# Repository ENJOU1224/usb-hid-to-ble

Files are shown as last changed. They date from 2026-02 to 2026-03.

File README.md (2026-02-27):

# USB HID to BLE Adapter (ENJOU Wireless Adapter)

一个基于 CH583 RISC-V 微控制器的 USB HID 到 BLE 适配器，可以将 USB 键盘和鼠标转换为蓝牙低功耗 (BLE) HID 设备。

## 项目概述

本项目实现了一个 USB Host 到 Bluetooth Low Energy (BLE) 的桥接器，将 USB HID（人机接口设备）键盘和鼠标输入转换为 BLE HID 设备功能。简单来说，它允许 USB 键盘或鼠标通过蓝牙无线使用。

### 主要功能

- **USB Host 功能**：
  - USB 2.0 Host 控制器支持
  - HID 设备枚举（键盘和鼠标）
  - 标准键盘和 NKRO（N键无冲）键盘数据解析
  - 鼠标数据解析（标准、NiZ 等多种格式）
  - USB 端点 DATA0/DATA1 同步处理

- **BLE 外围设备角色**：
  - GAP（通用访问配置文件）外围设备角色
  - GATT（通用属性配置文件）服务：
    - HID 服务（键盘和鼠标报告）
    - 电池服务（基于 ADC 电压测量）
    - 设备信息服务
    - 扫描参数服务
  - 安全配对的绑定管理器
  - 广播和连接管理

- **电池管理**：
  - 基于 ADC 的电池电压测量
  - 使用查找表计算电池电量百分比
  - 通过 BLE 电池服务报告电池电量
  - 临界电池电量监控

- **电源管理**：
  - DCDC 转换器支持低功耗运行
  - 多种睡眠模式（空闲、暂停、睡眠、关机）
  - 看门狗定时器确保系统安全

- **调试和日志**：
  - 可配置的 UART 调试输出
  - 独立的日志分类（系统、USB、BLE、电池、按键、鼠标）
  - LED 指示系统状态和 BLE 连接

## 硬件规格

- **微控制器**：CH582F（CH583 系列）
- **架构**：RISC-V (RV32IMAC)
- **内存**：
  - Flash：448KB
  - RAM：32KB
  - BLE 栈内存：6KB（可配置）
- **时钟**：60MHz 系统时钟（PLL）
- **USB**：USB 2.0 全速（12 Mbps）
- **BLE**：蓝牙低功耗 5.0

## 项目结构

```
usb-hid-to-ble/
├── APP/                    # 应用层
│   ├── hidkbd_main.c       # 主入口点和系统初始化
│   ├── usb_bridge.c        # USB 到 BLE 桥接逻辑
│   ├── hidkbd.c            # BLE HID 键盘/鼠标应用逻辑
│   ├── debug.c             # 调试日志工具
│   └── include/            # 应用头文件
├── HAL/                    # 硬件抽象层
│   ├── MCU.c               # 微控制器配置
│   ├── LED.c               # LED 控制
│   ├── KEY.c               # 按键/按钮处理
│   ├── SLEEP.c             # 睡眠/电源管理
│   ├── RTC.c               # 实时时钟
│   └── include/            # HAL 头文件
├── Profile/                # BLE 配置文件服务
│   ├── hidkbdservice.c     # HID 键盘/鼠标服务
│   ├── battservice.c       # 电池服务
│   ├── devinfoservice.c    # 设备信息服务
│   ├── scanparamservice.c  # 扫描参数服务
│   ├── hiddev.c            # HID 设备实现
│   └── include/            # 配置文件头文件
├── SRC/                    # 系统源文件
│   ├── StdPeriphDriver/    # CH583 外设驱动
│   ├── Startup/            # 启动代码 (startup_CH583.S)
│   ├── RVMSIS/             # RISC-V 核心支持
│   └── Ld/                 # 链接脚本 (Link.ld)
├── LIB/                    # 预编译库
│   ├── libCH58xBLE.a       # BLE 栈库
│   ├── CH58xBLE_LIB.h      # BLE 库头文件
│   ├── CH58xBLE_ROM.h      # 基于 ROM 的 BLE 函数
│   └── *.hex               # ROM 固件文件
└── HID_Keyboard.wvproj     # WCH IDE 项目配置
```

## 构建要求

- **开发环境**：WCH IDE（WCH-Link 调试器）
- **工具链**：RISC-V GCC 工具链
- **目标芯片**：CH582F（CH583 系列）
- **操作系统**：NoneOS（无操作系统）

## 构建配置

项目配置为 WCH IDE，具有以下设置：

- **目标**：CH582F (RISC-V, NoneOS)
- **优化**：大小优化
- **调试**：禁用（发布版本）
- **定义符号**：`DCDC_ENABLE=1`, `ENABLE_WATCHDOG=1`, `DEBUG=1`, `DEBUG_BATT=1`
- **库**：`ISP583`, `CH58xBLE`
- **链接脚本**：`Link.ld`（内存布局：FLASH 448KB @ 0x00000000, RAM 32KB @ 0x20000000）

## 硬件要求

- CH583 开发板
- USB Host 端口（用于连接 USB 键盘/鼠标）
- 电池测量电路（ADC 输入在 PA4）
- LED 指示灯（PB4 和 PB7）
- UART 调试输出（PA9 TX）

## 主要文件说明

1. **`hidkbd_main.c`** - 主应用程序入口点，系统初始化
2. **`usb_bridge.c`** - 核心 USB 到 BLE 转换逻辑
3. **`hidkbd.c`** - BLE HID 应用逻辑和电池管理
4. **`hidkbdservice.c`** - HID 服务实现，包含键盘/鼠标报告
5. **`battservice.c`** - 电池服务，包含电压测量
6. **`startup_CH583.S`** - RISC-V 启动代码和中断向量表
7. **`Link.ld`** - 内存布局和段定义
8. **`libCH58xBLE.a`** - 预编译的 BLE 栈库

## 使用说明

1. 将项目导入 WCH IDE
2. 连接 CH583 开发板
3. 编译并下载固件到开发板
4. 连接 USB 键盘/鼠标到开发板的 USB Host 端口
5. 通过蓝牙连接到适配器（设备名称：ENJOU BLE Adapter）

## 调试功能

项目包含可配置的调试输出，可以通过 UART 查看系统状态：

- `DEBUG_SYS` - 系统初始化、主循环、看门狗日志
- `DEBUG_USB` - USB 枚举和通信日志
- `DEBUG_BLE` - BLE 状态和连接日志
- `DEBUG_BATT` - 电池电压和电量日志
- `DEBUG_KEY` - 键盘按键事件日志
- `DEBUG_MOUSE` - 鼠标移动事件日志
- `ENABLE_LED` - 启用 LED 指示灯

## 项目状态

这是一个功能完整的嵌入式固件项目，成功实现了 USB 到 BLE 适配器。代码结构清晰，注释完善，具有良好的硬件抽象层分离。

## 许可证

本项目基于 WCH 官方库和开源组件开发，具体许可证请参考相关库文件。

## 贡献

欢迎提交问题和拉取请求。

## 联系方式

如有问题或建议，请通过 GitHub Issues 联系。

---

**ENJOU Wireless Adapter** - 将您的 USB 设备无线化！

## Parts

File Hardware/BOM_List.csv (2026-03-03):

No. | Quantity | Comment | Designator | Footprint | Value | Manufacturer Part | Manufacturer | Supplier Part | Supplier
1 | 1 | XL-2012UBC | BLE | LED0805-RD |  | XL-2012UBC | XINGLIGHT(成兴光) | C965817 | LCSC
2 | 3 | TS-1088-AR02016 | BOOT,RST,USER | SW-SMD_L3.9-W3.0-P4.45 |  | TS-1088-AR02016 | XUNPU(讯普) | C720477 | LCSC
3 | 1 | BH-18650-B1BA002 | BT1 | BATTERY-SMD_18650-1S-L77.1-W20.7-1 |  | BH-18650-B1BA002 | MYOUNG(美阳) | C2988620 | LCSC
4 | 2 | 100nF | C1,C11 | C0805 | 100nF | CC0805KRX7R9BB104 | YAGEO(国巨) | C49678 | LCSC
5 | 1 | 4.7uF | C2 | C0805 | 4.7uF | CL21A475KAQNNNE | SAMSUNG(三星) | C1779 | LCSC
6 | 3 | 10uF | C3,C9,C10 | C0805 | 10uF | CL21A106KAYNNNE | SAMSUNG(三星) | C15850 | LCSC
7 | 2 | 1uF | C4,C5 | C0805 | 1uF | CL21B105KBFNNNE | SAMSUNG(三星) | C28323 | LCSC
8 | 3 | 22uF | C6,C7,C8 | C0805 | 22uF | CL21A226MAQNNNE | SAMSUNG(三星) | C45783 | LCSC
9 | 1 | NCD0805R1 | CHARGING | LED0805-RD |  | NCD0805R1 | 国星光电 | C84256 | LCSC
10 | 1 | KT-0805G | FULL | LED0805-R-RD |  | KT-0805G | KENTO | C2297 | LCSC
11 | 1 | 1x4P 间距:2.54mm 方针 直插 | H1 | HDR-TH_4P-HX-PH254-01-04-Z-L11.5 |  | HX PH254-01-04-Z-L11.5 straight pin header | hanxia(韩下) | C52016392 | LCSC
12 | 1 | 2.2uH | L1 | IND-SMD_L2.5-W2.0_MHCHL2520 | 2.2uH | FTC252012S2R2MBCA | cjiang(长江微电) | C5832372 | LCSC
13 | 4 | 1kΩ | R1,R3,R11,R12 | R0805 | 1kΩ | 0805W8F1001T5E | UNI-ROYAL(厚声) | C17513 | LCSC
14 | 2 | 100Ω | R2,R5 | R0805 | 100Ω | 0805W8F1000T5E | UNI-ROYAL(厚声) | C17408 | LCSC
15 | 1 | 500mΩ | R4 | R0805 | 500mΩ | 0805W8F500LT5E | UNI-ROYAL(厚声) | C28319 | LCSC
16 | 1 | 51kΩ | R6 | R0603 | 51kΩ | 0603WAF5102T5E | UNI-ROYAL(厚声) | C23196 | LCSC
17 | 1 | 82kΩ | R7 | R0603 | 82kΩ | 0603WAF8202T5E | UNI-ROYAL(厚声) | C23254 | LCSC
18 | 1 | 2Ω | R8 | R0805 | 2Ω | 0805W8F200KT5E | UNI-ROYAL(厚声) | C17606 | LCSC
19 | 2 | 5.1kΩ | R9,R10 | R0805 | 5.1kΩ | 0805W8F5101T5E | UNI-ROYAL(厚声) | C27834 | LCSC
20 | 2 | 100kΩ | R13,R14 | R0805 | 100kΩ | 0805W8F1003T5E | UNI-ROYAL(厚声) | C149504 | LCSC
21 | 1 | SK12D07VG5 | SW1 | SW-TH_SK12D07VG5-1 |  | SK12D07VG5 | SHOU HAN(首韩) | C431548 | LCSC
22 | 1 | KT-0805Y | SYS | LED0805-R-RD |  | KT-0805Y | KENTO | C2296 | LCSC
23 | 1 | IP2312-4V35 | U1 | ESOP-8_L4.9-W3.9-P1.27-LS6.0-BL-EP |  | IP2312-4V35 | INJOINIC(英集芯) | C605433 | LCSC
24 | 1 | XB8089A0 | U2 | ESOP-8_L4.9-W3.9-P1.27-LS6.0-BL-EP |  | XB8089A0 | xysemi(赛芯微) | C2759990 | LCSC
25 | 1 | XC6206P332MR-G | U4 | SOT-23-3_L2.9-W1.6-P1.90-LS2.8-BR |  | XC6206P332MR-G | TOREX(特瑞仕) | C5446 | LCSC
26 | 1 | ETA1061V50S2G | U5 | SOT-23-6_L2.9-W1.6-P0.95-LS2.8-BR |  | ETA1061V50S2G | ETA(钰泰) | C7465524 | LCSC
27 | 1 | 1uH | U6 | IND-SMD_L2.5-W2.0-VLS252012CX-150M | 1uH | FTC252012S1R0MBCA | cjiang(长江微电) | C5832370 | LCSC
28 | 1 | ch582f 最小系统板 | U7 | ch582f 最小系统板修改
29 | 1 | TYPE-C 16PIN 2MD(073) | USB1 | USB-C-SMD_TYPE-C-6PIN-2MD-073 |  | TYPE-C 16PIN 2MD(073) | SHOU HAN(首韩) | C2765186 | LCSC
30 | 1 | AF 90° WJDG | USB2 | USB-A-TH_AF-WJDG |  | AF 90° WJDG | SHOU HAN(首韩) | C456018 | LCSC

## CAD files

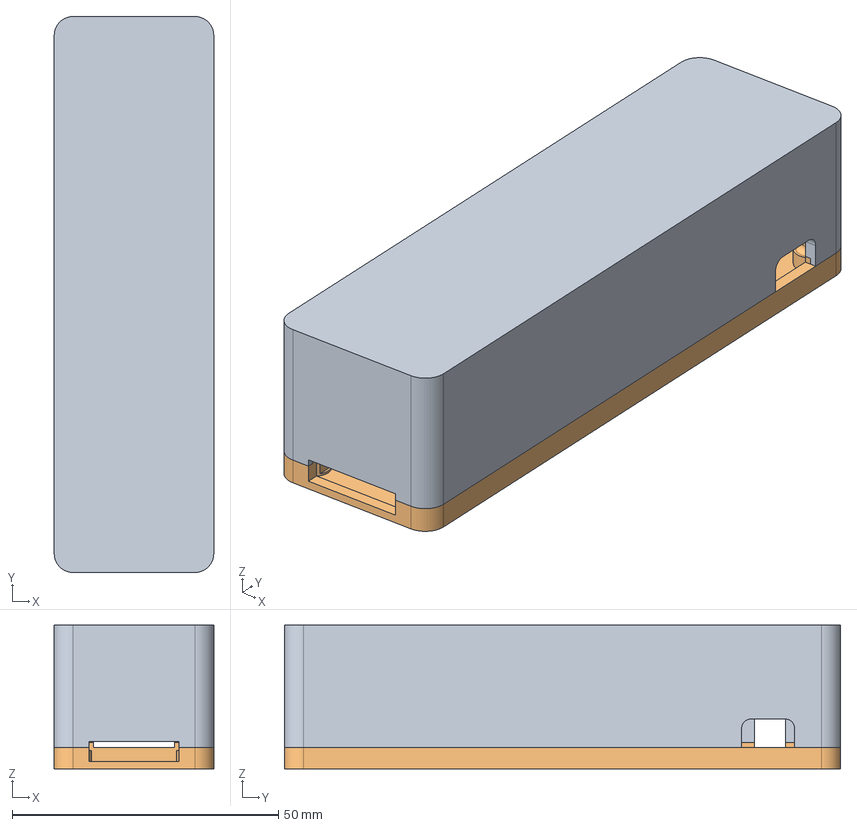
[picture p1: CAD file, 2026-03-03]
Enclosure/Case_Full_Assembly.step
30.0 x 104.4 x 27.0 mm

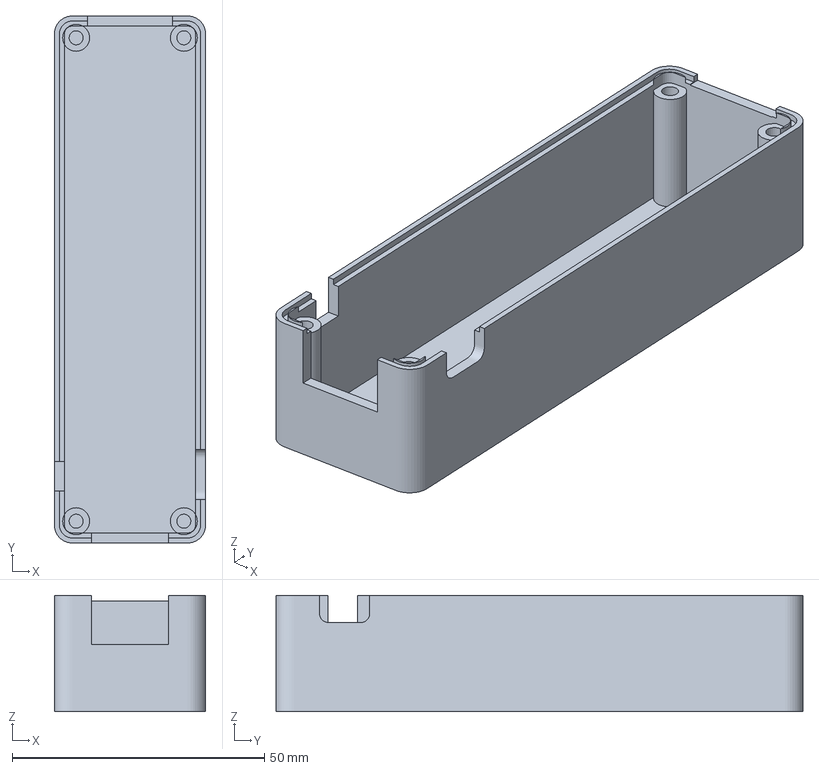
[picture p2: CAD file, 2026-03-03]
Enclosure/top.3mf
30.0 x 104.4 x 23.0 mm

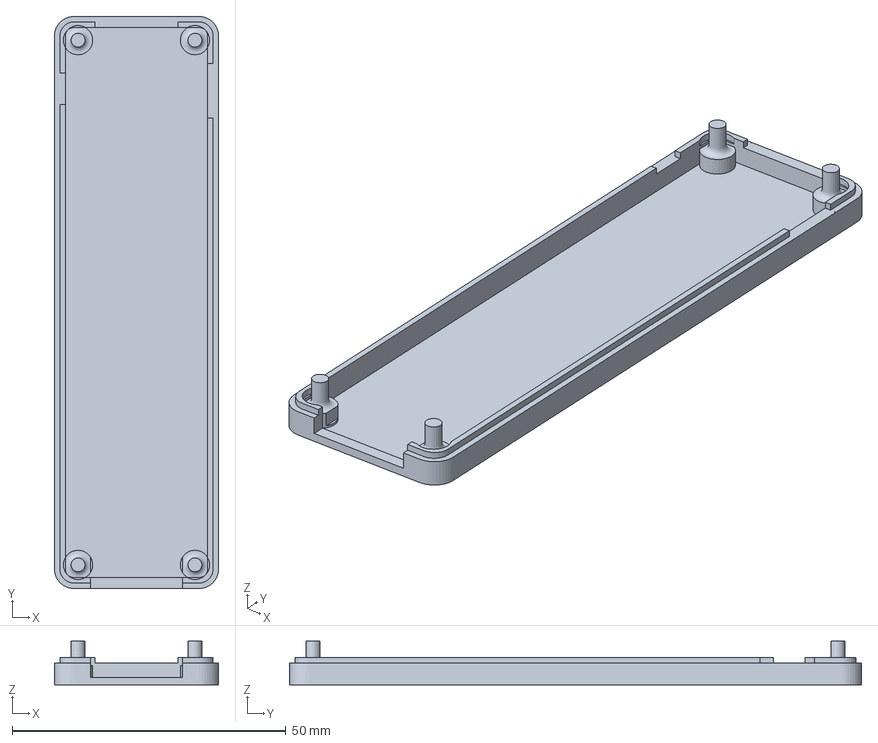
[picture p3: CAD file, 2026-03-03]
Enclosure/bottom.3mf
30.0 x 104.4 x 8.00 mm

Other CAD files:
Enclosure/STLs/bottom.stl
Enclosure/STLs/top.stl

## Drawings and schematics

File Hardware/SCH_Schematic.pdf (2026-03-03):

## 锂电池保护

# DC-DC 升压

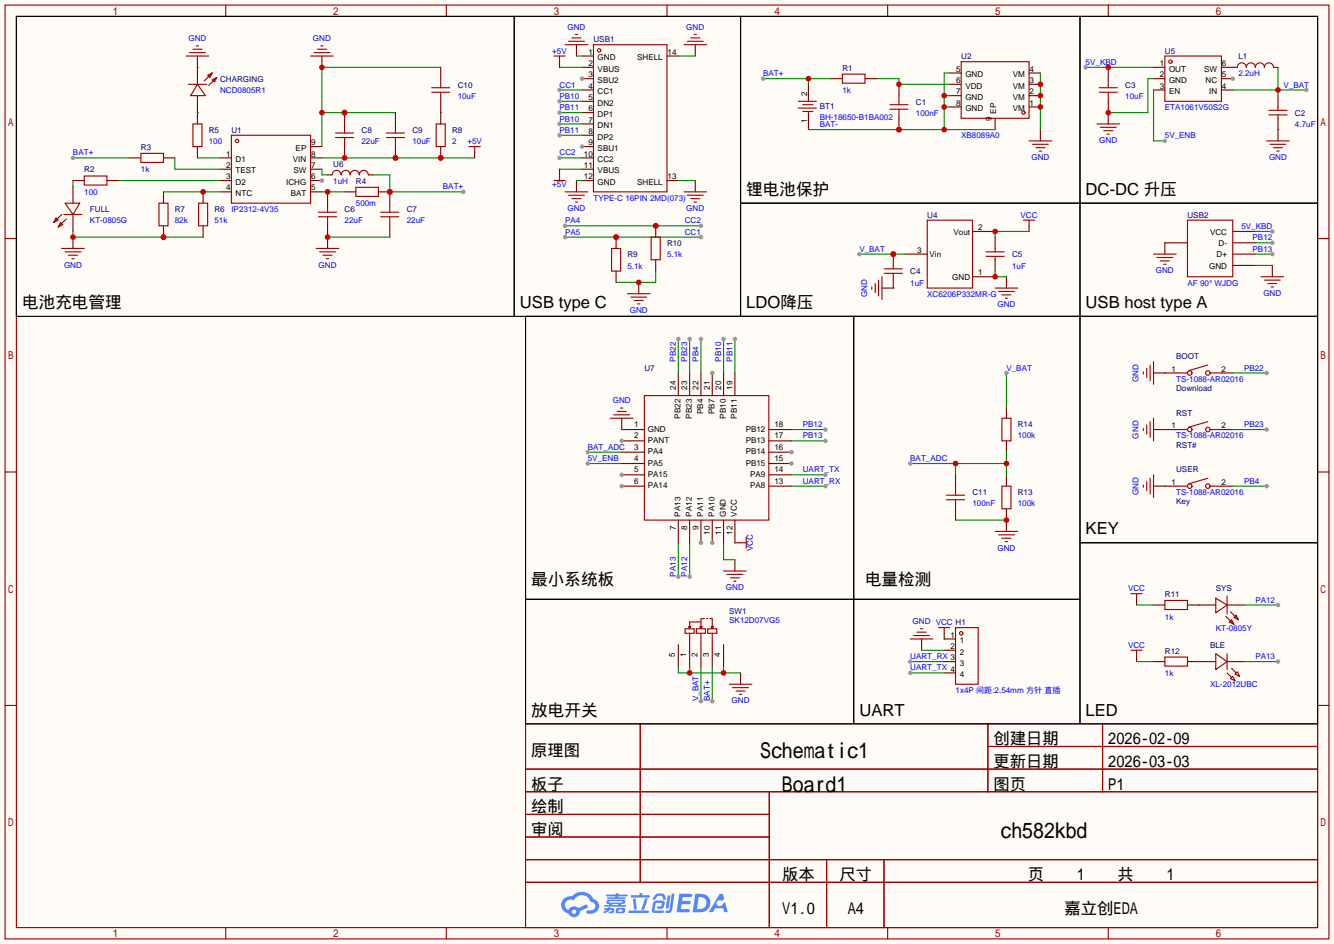
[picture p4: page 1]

原理图 | Schematic1 | 创建日期 | 2026-02-09

更新日期 | 2026-03-03

板子 | Board1 | 图页 | P1
绘制 | | ch582kbd
审阅

V1.0 | A4 | 嘉立创EDA

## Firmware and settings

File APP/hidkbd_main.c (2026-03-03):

/*********************************************************************
 * File Name          : main.c
 * Author             : DIY User & AI Assistant
 * Version            : V9.1 (Optimized & Annotated)
 * Description        : NiZ 键盘蓝牙适配器主程序入口
 *                      - 系统时钟与电源配置
 *                      - 任务调度器 (TMOS) 主循环
 *                      - USB 与 BLE 协议栈的协同调度
 *                      - 硬件看门狗 (Watchdog) 保护
 *********************************************************************/

#include "CONFIG.h"
#include "HAL.h"
#include "hiddev.h"
#include "hidkbd.h"
#include "debug.h"

// ===================================================================
// ? 外部引用 (External References)
// ===================================================================
extern void USB_Bridge_Init(void);
extern void USB_Bridge_Poll(void);

// ===================================================================
// ? 全局内存配置 (Memory Config)
// ===================================================================

// BLE 协议栈专用堆内存 (必须 4字节对齐)
__attribute__((aligned(4))) uint32_t MEM_BUF[BLE_MEMHEAP_SIZE / 4];

// [可选] 自定义 MAC 地址
// 如果注释掉，芯片将使用出厂预烧录的唯一 MAC
#if(defined(BLE_MAC)) && (BLE_MAC == TRUE)
    const uint8_t MacAddr[6] = {0x84, 0xC2, 0xE4, 0x03, 0x02, 0x02};
#endif

__HIGH_CODE
__attribute__((noinline))
void Main_Circulation()
{
    while(1)
    {
        // 1. 蓝牙协议栈调度 
        TMOS_SystemProcess();

        // 2. 喂狗 
        #ifdef ENABLE_WATCHDOG
            R8_WDOG_COUNT = 0; 
        #endif
    }
}
// ===================================================================
// ? 程序入口 (Main Entry)
// ===================================================================
int main(void)
{
    // ----------------------------------------------------------------
    // 1. 基础硬件与时钟初始化
    // ----------------------------------------------------------------
    
    // DCDC 电源配置 (降低功耗)
#if(defined(DCDC_ENABLE)) && (DCDC_ENABLE == TRUE)
    PWR_DCDCCfg(ENABLE); 
#else
    PWR_DCDCCfg(DISABLE); // 无电感设计必须禁用 DCDC
#endif
    
    // 设置系统主频为 60MHz
    // 推荐 60MHz 而非 48MHz，因为 USB Host 需要较快的响应速度处理中断
    SetSysClock(CLK_SOURCE_PLL_60MHz);

    // ----------------------------------------------------------------
    // 2. GPIO 初始化 (LED)
    // ----------------------------------------------------------------

    // ----------------------------------------------------------------
    // 3. 调试串口初始化
    // ----------------------------------------------------------------
#ifdef DEBUG
    GPIOA_SetBits(bTXD1); // TXD1 (PA9) 置高
    GPIOA_ModeCfg(bTXD1, GPIO_ModeOut_PP_5mA);
    UART1_DefInit();      // 默认波特率 (通常 115200)
#endif

    LOG_SYS("\n================================\n");
    LOG_SYS("   ENJOU Wireless Adapter V9.1  \n");
    LOG_SYS("   Build: %s %s       \n", __DATE__, __TIME__);
    LOG_SYS("================================\n");

    // ----------------------------------------------------------------
    // 4. 蓝牙协议栈初始化 (Standard Sequence)
    // ----------------------------------------------------------------
    LOG_SYS("[Init] BLE Stack...\n");
    CH58X_BLEInit();            // 库文件初始化
    HAL_Init();                 // 硬件抽象层初始化
    GAPRole_PeripheralInit();   // 角色初始化
    HidDev_Init();              // HID 服务层初始化
    HidEmu_Init();              // 用户应用层 (键盘逻辑) 初始化

    // ----------------------------------------------------------------
    // 5. USB Host 初始化 (Critical)
    // ----------------------------------------------------------------
    // 务必放在 BLE 初始化之后，避免 USB 初始化的延时影响 BLE 时序
    LOG_SYS("[Init] USB Host...\n");
    USB_Bridge_Init(); 

    // ----------------------------------------------------------------
    // 6. 看门狗配置 (System Safety)
    // ----------------------------------------------------------------
#ifdef ENABLE_WATCHDOG
    // R8_RST_WDOG_CTRL 寄存器说明:
    // RB_WDOG_RST_EN: 允许看门狗复位系统
    // RB_WDOG_INT_EN: 允许看门狗产生中断 (通常配合复位一起开)
    // 0x80          : 预分频值，决定溢出时间 (约 1.6s @ 32KHz LSI)
    R8_RST_WDOG_CTRL = RB_WDOG_RST_EN | RB_WDOG_INT_EN; 
    LOG_SYS("[Init] Watchdog Enabled (1.6s)\n");
#endif

    // ----------------------------------------------------------------
    // 7. 启动完成
    // ----------------------------------------------------------------
    LOG_SYS(">> System Running <<\n");

    // 跳转至死循环
    Main_Circulation();
}

/******************************** endfile @ main ******************************/

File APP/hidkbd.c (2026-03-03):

/*********************************************************************
 * File Name          : hidkbd.c
 * Author             : DIY User & AI Assistant
 * Description        : NiZ 蓝牙键盘主应用逻辑
 *                      - 集成 HID 键盘/鼠标复合设备
 *                      - 集成电池电量采集 (ADC) 与上报
 *                      - 状态指示灯控制
 *********************************************************************/

#include "CONFIG.h"
#include "devinfoservice.h"
#include "battservice.h"
#include "hidkbdservice.h"
#include "hiddev.h"
#include "hidkbd.h"
#include "debug.h"

// ===================================================================
// 蓝牙参数配置 (BLE Configuration)
// ===================================================================
#define DEFAULT_HID_IDLE_TIMEOUT             60000
#define DEFAULT_DESIRED_MIN_CONN_INTERVAL    8
#define DEFAULT_DESIRED_MAX_CONN_INTERVAL    8
#define DEFAULT_DESIRED_SLAVE_LATENCY        0
#define DEFAULT_DESIRED_CONN_TIMEOUT         500
#define DEFAULT_PASSCODE                     0
#define DEFAULT_PAIRING_MODE                 GAPBOND_PAIRING_MODE_WAIT_FOR_REQ
#define DEFAULT_MITM_MODE                    FALSE
#define DEFAULT_BONDING_MODE                 TRUE
#define DEFAULT_IO_CAPABILITIES              GAPBOND_IO_CAP_NO_INPUT_NO_OUTPUT
#define DEFAULT_BATT_CRITICAL_LEVEL          6

// ===================================================================
// 硬件引脚配置 (Hardware Config)
// ===================================================================

// 电池检测 (ADC -> PA4)
#define BATT_ADC_PIN         GPIO_Pin_4
#define BATT_ADC_CHANNEL     0            // ADC Channel 0

// ===================================================================
// 蓝牙广播数据
// ===================================================================

// 设备名称
static const uint8_t attDeviceName[] = "ENJOU BLE Adapter";

// 广播数据 (Flags + Appearance + Local Name)
static uint8_t advertData[] = {
    0x02, GAP_ADTYPE_FLAGS, GAP_ADTYPE_FLAGS_LIMITED | GAP_ADTYPE_FLAGS_BREDR_NOT_SUPPORTED,
    0x03, GAP_ADTYPE_APPEARANCE, LO_UINT16(GAP_APPEARE_HID_KEYBOARD), HI_UINT16(GAP_APPEARE_HID_KEYBOARD),
    0x0A, GAP_ADTYPE_LOCAL_NAME_COMPLETE,
    'E', 'N', 'J', 'O', 'U', ' ', 'B', 'L', 'E'
};

// 扫描响应数据 (Conn Interval + UUIDs + TX Power)
static uint8_t scanRspData[] = {
    0x05, GAP_ADTYPE_SLAVE_CONN_INTERVAL_RANGE,
    LO_UINT16(DEFAULT_DESIRED_MIN_CONN_INTERVAL), HI_UINT16(DEFAULT_DESIRED_MIN_CONN_INTERVAL),
    LO_UINT16(DEFAULT_DESIRED_MAX_CONN_INTERVAL), HI_UINT16(DEFAULT_DESIRED_MAX_CONN_INTERVAL),
    0x05, GAP_ADTYPE_16BIT_MORE,
    LO_UINT16(HID_SERV_UUID), HI_UINT16(HID_SERV_UUID),
    LO_UINT16(BATT_SERV_UUID), HI_UINT16(BATT_SERV_UUID),
    0x02, GAP_ADTYPE_POWER_LEVEL, 0
};

// HID 配置参数
static hidDevCfg_t hidEmuCfg = {
    DEFAULT_HID_IDLE_TIMEOUT,
    HID_FEATURE_FLAGS
};

// ===================================================================
// 全局变量
// ===================================================================

static uint8_t  hidEmuTaskId    = INVALID_TASK_ID;       // TMOS 任务ID
static uint16_t hidEmuConnHandle = GAP_CONNHANDLE_INIT;  // 连接句柄

static uint8_t is_ble_sleeping  = FALSE;  // 是否处于软休眠（蓝牙关闭）状态
static uint8_t is_sys_led_startup = TRUE; // 是否还在上电 SYS 灯长亮阶段

uint8_t is_usb_idle = FALSE;  // USB 30秒空闲标志

// 电池相关
static uint8_t      last_batt_percent   = 0;  // 上次上报的电量
static signed short ADC_RoughCalib_Value = 0; // ADC 校准偏移值

// 放电曲线查找表 (mV -> %), 线性插值
typedef struct { uint16_t mv; uint8_t pct; } BattMap;
static const BattMap batt_table[] = {
    {4200, 100},
    {4100,  95},
    {4070,  90},
    {4000,  80},
    {3910,  70},
    {3840,  60},
    {3750,  50},
    {3660,  40},
    {3600,  30},
    {3510,  20},
    {3450,  15},
    {3380,  10},
    {3340,   8},
    {3300,   6},
    {3260,   4},
    {3220,   2},
    {3180,   1},
    {3100,   0},
    {0,      0}  // 结束符（边界保护）
};
#define BATT_TABLE_COUNT  (sizeof(batt_table) / sizeof(BattMap))

// ===================================================================
// 内部函数声明
// ===================================================================
static void    HidEmu_ProcessTMOSMsg(tmos_event_hdr_t *pMsg);
static void    HidEmu_MeasureBattery(void);
static void    HidEmu_StateCB(gapRole_States_t newState, gapRoleEvent_t *pEvent);
static uint8_t HidEmu_RptCB(uint8_t id, uint8_t type, uint16_t uuid, uint8_t oper, uint16_t *pLen, uint8_t *pData);

// 回调结构体
static hidDevCB_t hidEmuHidCBs = {
    HidEmu_RptCB,
    NULL,  // EvtCB 未使用
    NULL,
    HidEmu_StateCB
};

// ===================================================================
// 初始化
// ===================================================================
void HidEmu_Init()
{
    hidEmuTaskId = TMOS_ProcessEventRegister(HidEmu_ProcessEvent);

    // 1. 初始化 LED 引脚 (推挽输出)
    GPIOA_ModeCfg(SYS_LED_PIN | BLE_LED_PIN, GPIO_ModeOut_PP_5mA);

    // 2. 初始化 USER 按键 (上拉输入)
    GPIOB_ModeCfg(USER_KEY_PIN, GPIO_ModeIN_PU);

    // 3. 上电时 SYS 长亮
    is_sys_led_startup = TRUE;
    SYS_LED_ON();
    BLE_LED_OFF();
    tmos_start_task(hidEmuTaskId, HID_SYS_LED_OFF_EVT, TIME_SYS_LED_STARTUP);

    // 4. 启动按键轮询
    tmos_start_task(hidEmuTaskId, HID_USER_KEY_POLL_EVT, TIME_KEY_POLL);

    // 5. GAP 广播与通用配置
    {
        uint8_t initial_advertising_enable = TRUE;
        GAPRole_SetParameter(GAPROLE_ADVERT_ENABLED, sizeof(uint8_t), &initial_advertising_enable);
        GAPRole_SetParameter(GAPROLE_ADVERT_DATA, sizeof(advertData), advertData);
        GAPRole_SetParameter(GAPROLE_SCAN_RSP_DATA, sizeof(scanRspData), scanRspData);
    }
    GGS_SetParameter(GGS_DEVICE_NAME_ATT, sizeof(attDeviceName), (void *)attDeviceName);

    // 6. 安全与配对配置 (Bond Manager)
    {
        uint32_t passkey = DEFAULT_PASSCODE;
        uint8_t  pairMode = DEFAULT_PAIRING_MODE;
        uint8_t  mitm     = DEFAULT_MITM_MODE;
        uint8_t  ioCap    = DEFAULT_IO_CAPABILITIES;
        uint8_t  bonding  = DEFAULT_BONDING_MODE;

        GAPBondMgr_SetParameter(GAPBOND_PERI_DEFAULT_PASSCODE, sizeof(uint32_t), &passkey);
        GAPBondMgr_SetParameter(GAPBOND_PERI_PAIRING_MODE,     sizeof(uint8_t),  &pairMode);
        GAPBondMgr_SetParameter(GAPBOND_PERI_MITM_PROTECTION,  sizeof(uint8_t),  &mitm);
        GAPBondMgr_SetParameter(GAPBOND_PERI_IO_CAPABILITIES,  sizeof(uint8_t),  &ioCap);
        GAPBondMgr_SetParameter(GAPBOND_PERI_BONDING_ENABLED,  sizeof(uint8_t),  &bonding);
    }

    // 7. 注册 GATT 服务
    {
        uint8_t critical = DEFAULT_BATT_CRITICAL_LEVEL;
        Batt_SetParameter(BATT_PARAM_CRITICAL_LEVEL, sizeof(uint8_t), &critical);
        Hid_AddService();
        HidDev_Register(&hidEmuCfg, &hidEmuHidCBs);
    }

    // 8. ADC 硬件初始化 (电量检测)
    {
        GPIOA_ModeCfg(BATT_ADC_PIN, GPIO_ModeIN_Floating);
        ADC_ExtSingleChSampInit(SampleFreq_3_2, ADC_PGA_1_2);
        ADC_RoughCalib_Value = ADC_DataCalib_Rough();
        LOG_BATT("ADC Init. Offset: %d\n", ADC_RoughCalib_Value);

        tmos_start_task(hidEmuTaskId, START_BATT_READ_EVT, TIME_BATT_BOOT_DELAY);
    }
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

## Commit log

2026-01-21 目前是跑通了有线转蓝牙，暂存一下，为接入电量管理做准备
2026-01-21 目前电量检测和电量上报跑通了，在尝试看看板子上的LED可不可用
2026-01-21 增加LED显示状态逻辑
2026-01-21 初步增加了鼠标支持，我的雷柏没问题，罗技和我的键盘的鼠标模拟貌似都有不识别按下只识别抬起的问题
2026-01-21 鼠标支持没问题了，准备ai重写一下
2026-01-23 面包板到了，调试了一下电池电压检测部分，修正了电压检测部分的问题adc增益配置不正确以及电压算法不正确的问题
2026-01-23 用ai优化了一下代码的可读性和去掉了一些冗余逻辑。
2026-02-27 不知道哪里改了，但是应该是能跑的
2026-02-27 Untrack all files to reset according to new .gitignore
    [battservice.c, hidkbd.c, hidkbd.h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]
2026-02-27 修了一下.gitignore，现在全是newfile了，有点头疼。把依赖也加进来追踪了。
2026-02-27 添加 README.md 到 .gitignore 排除名单，并将 README.md 加入版本控制
2026-03-01 主要几个文件转成UTF-8了
2026-03-01 增加了SYS BLE的LED逻辑，增加了复位键USER的处理逻辑
2026-03-02 增加了休眠逻辑，自动断联蓝牙的休眠逻辑是成功的，但是USB SUSPEND还没调通
2026-03-02 调不通USB SUSPEND，直接软休眠了
2026-03-03 动态轮询速率逻辑增加
2026-03-03 使用Antigravity优化了注释和项目配置
2026-03-03 暂时定版，去掉了usb suspend相关逻辑，我的键盘suspend状态下一点不省电。软休眠市场改为10分钟
2026-03-03 原理图、PCB和3D打印外壳添加上传
    [BOM_List.csv, bottom.3mf, bottom.stl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]
2026-03-03 增加step文件
    [Case_Full_Assembly.step]
